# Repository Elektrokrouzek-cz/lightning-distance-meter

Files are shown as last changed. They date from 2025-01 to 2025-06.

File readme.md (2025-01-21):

# Lightning distance meter
This is the construction of lightning distance meter. It is based on NE555 timer 
and 4017 logical circuits. All components are in THT packages.

PCB is 2-layer and was designed using KiCad 8. Fabrication output for JLCPCB is in 
gerber folder.

## How it works
This meter measures distance between lightning and thunder by measuring the time.
Speed of sound is 343 m/s therefore it takes approx. 291ms to the sound to travel
100m (this is the period of NE555 timer). 
User pushes Start button when lightning occurs and then presses Stop button when 
hears the thunder. LED diodes show measured distance. Maximal measurable distance is 9.9km. 

**Happy soldering!**

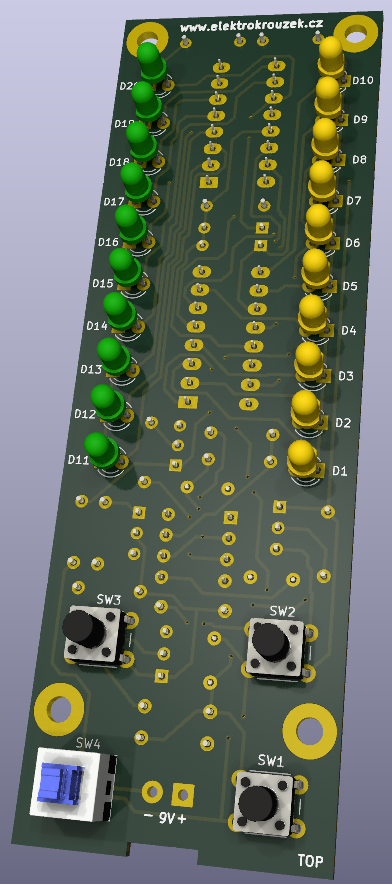
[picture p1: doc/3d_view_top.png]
3D view

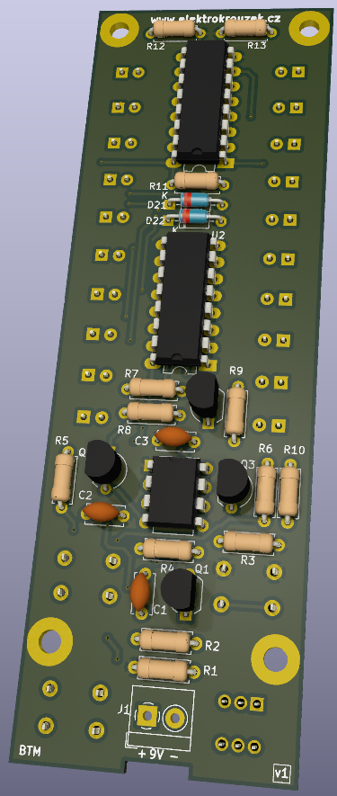
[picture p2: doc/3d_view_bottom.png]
3D view


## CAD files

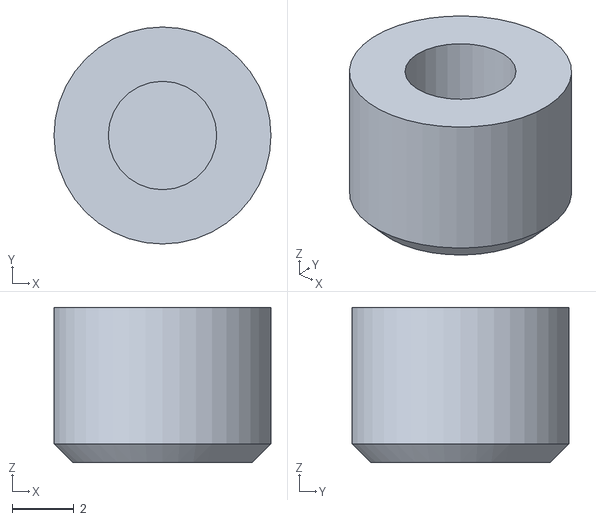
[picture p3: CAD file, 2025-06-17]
3d/storm_button.stl
7.00 x 7.00 x 5.00

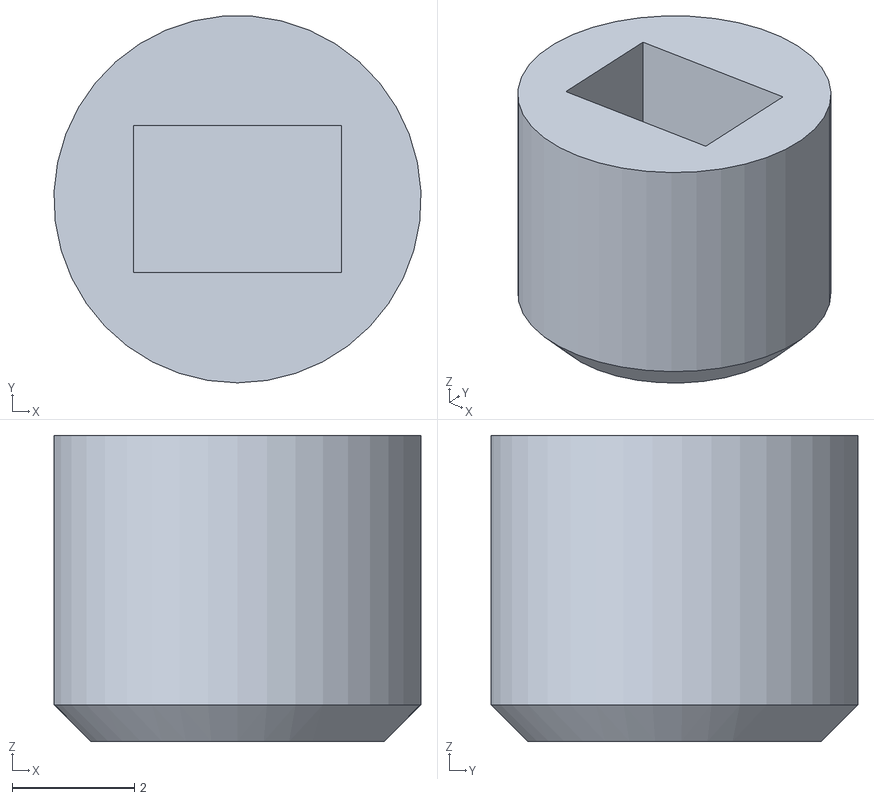
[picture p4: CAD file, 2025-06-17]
3d/storm_switch.stl
6.00 x 5.99 x 5.00

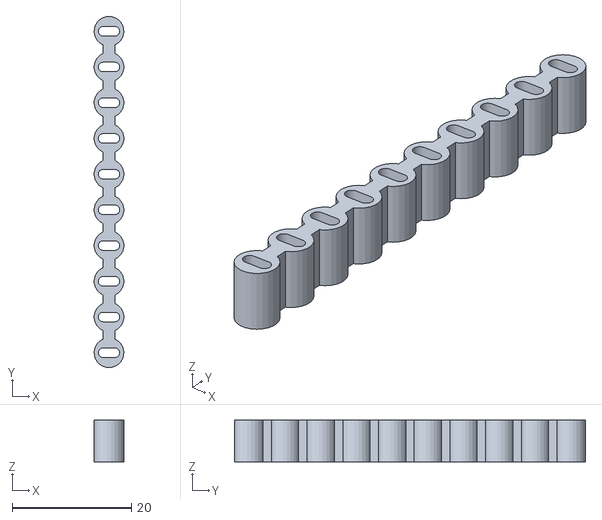
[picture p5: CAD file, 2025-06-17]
3d/storm_spacer.stl
4.96 x 59.0 x 7.00

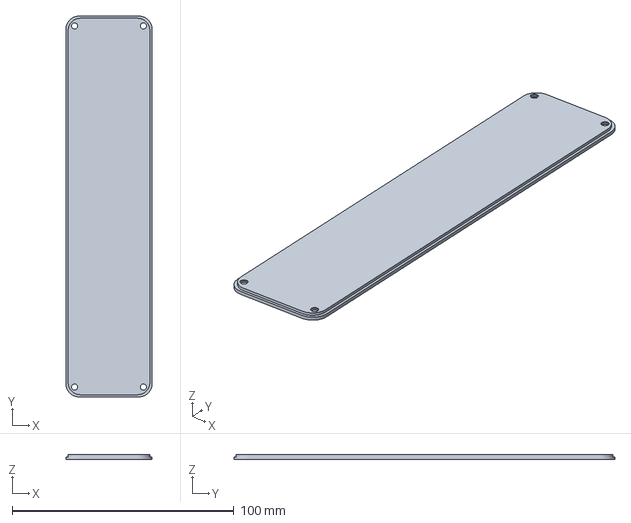
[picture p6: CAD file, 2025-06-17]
3d/storm_cover.3mf
39.0 x 172.0 x 2.20 mm

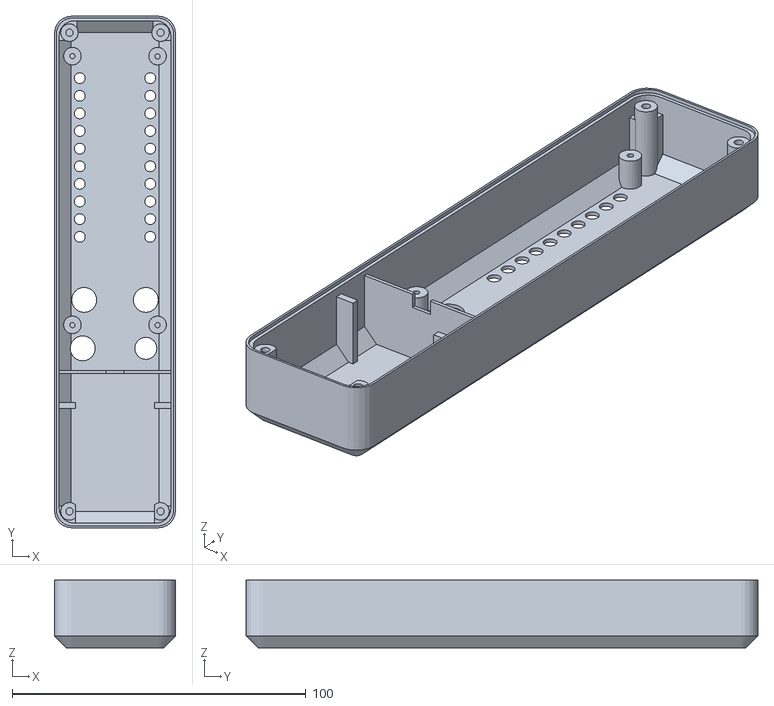
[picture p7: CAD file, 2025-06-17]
3d/storm_housing.stl
41.2 x 174.2 x 23.0

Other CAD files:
3d/storm.f3d

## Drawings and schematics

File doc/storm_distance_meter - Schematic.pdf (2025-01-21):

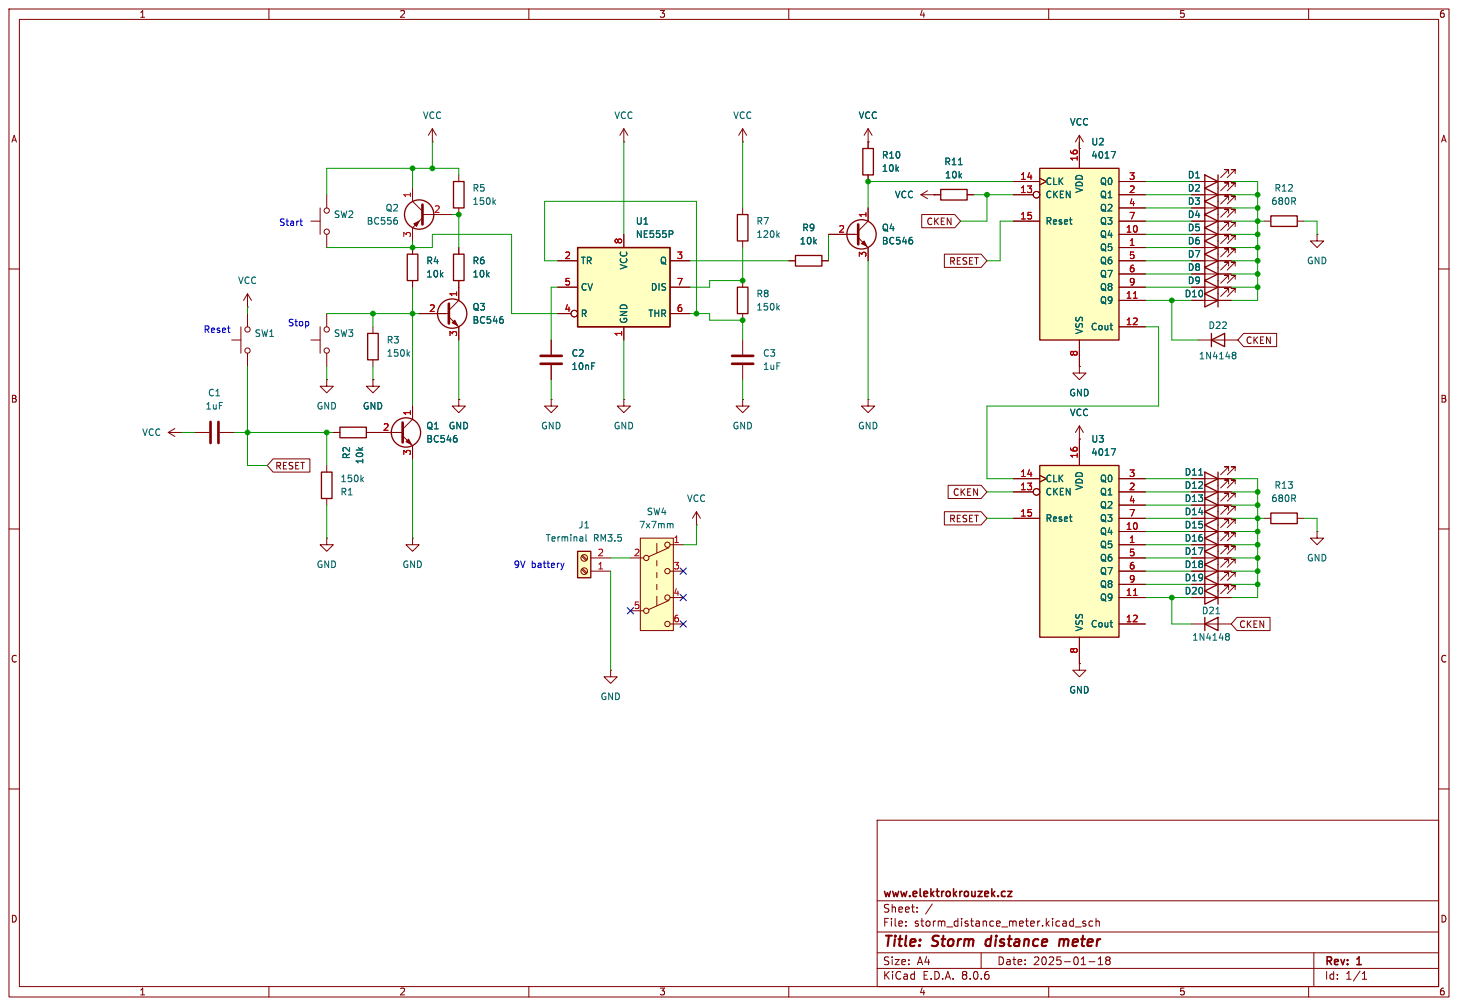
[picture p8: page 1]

3 Q3 BC546 VCC Q5 1 Q4 10 Q9 11 Cout 12 CKEN 13 CLK 14 Reset 15 VDD 16 Q1 2 Q0 3 Q2 4 Q6 5 Q7 6 Q3 7 VSS

Id: 1/1 Title: Storm distance meter File: storm_distance_meter.kicad_sch Sheet: / www.elektrokrouzek.cz

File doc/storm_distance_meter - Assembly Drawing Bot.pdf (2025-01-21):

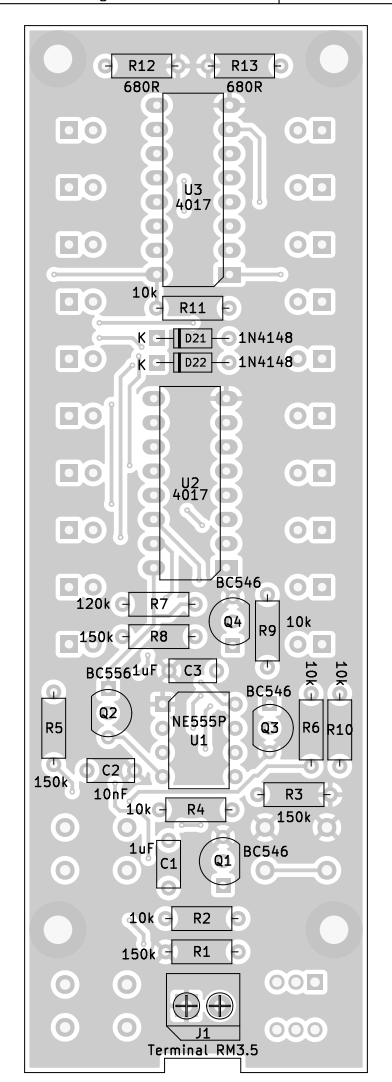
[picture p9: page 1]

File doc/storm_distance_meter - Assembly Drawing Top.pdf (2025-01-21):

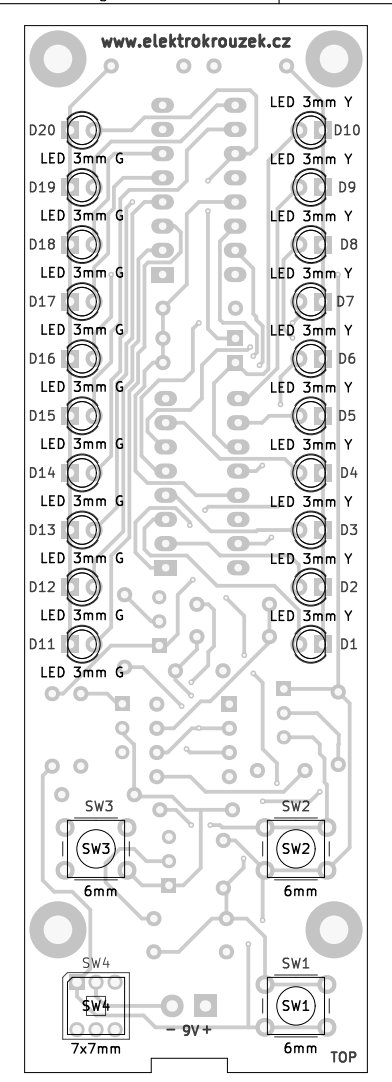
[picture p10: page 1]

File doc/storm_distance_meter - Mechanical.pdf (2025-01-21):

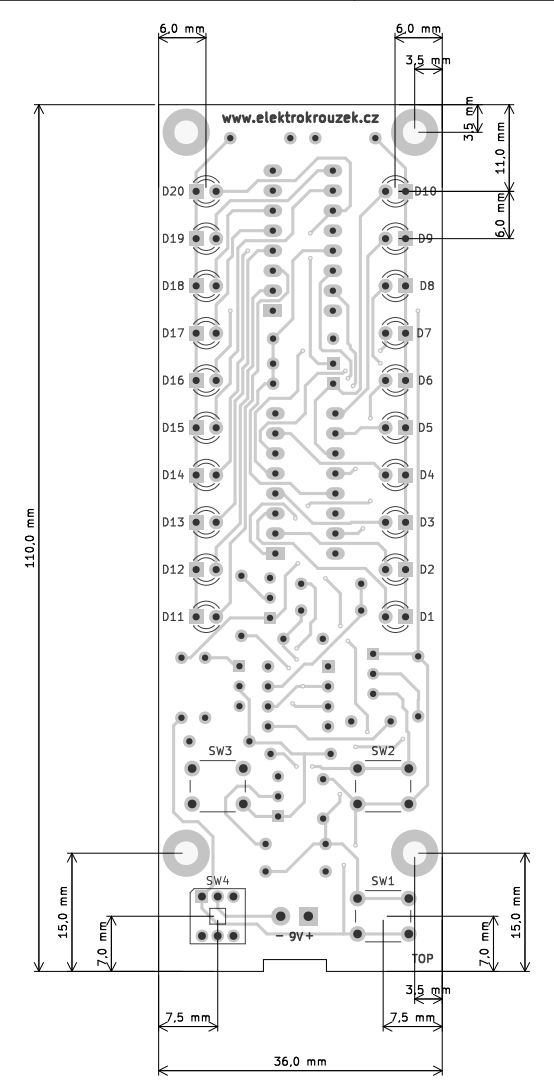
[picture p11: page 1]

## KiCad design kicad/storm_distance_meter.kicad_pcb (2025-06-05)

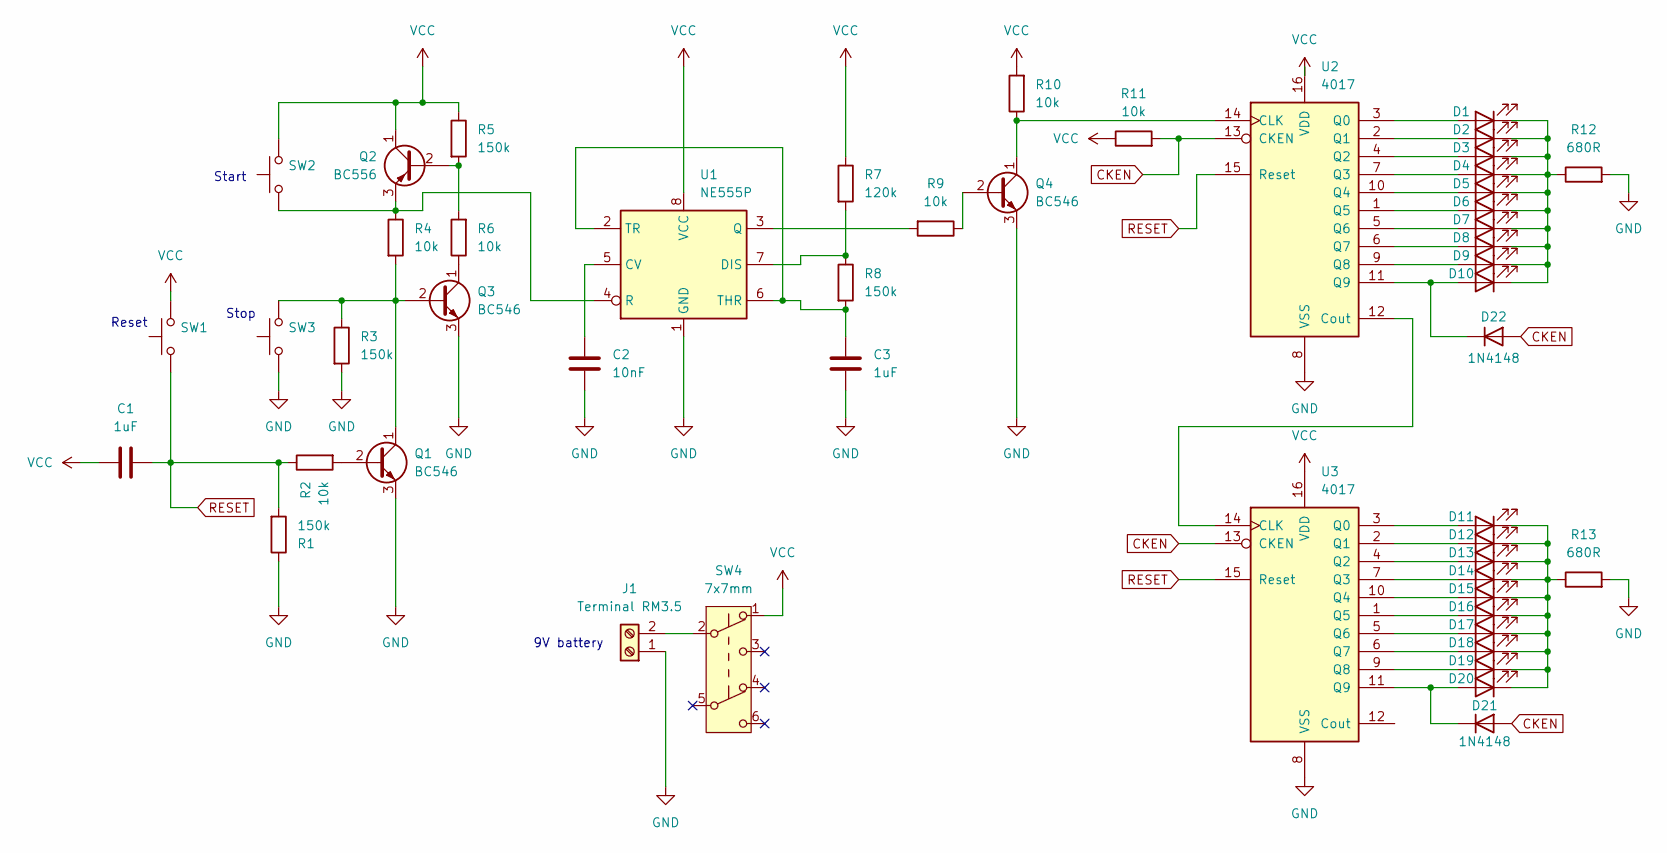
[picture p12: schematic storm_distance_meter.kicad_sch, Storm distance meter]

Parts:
C1, C3: 1uF; C_Disc_D5.0mm_W2.5mm_P5.00mm
C2: 10nF; C_Disc_D5.0mm_W2.5mm_P5.00mm
D1, D2, D3, D4, D5, D6, D7, D8, D9, D10: LED 3mm Y; LED_D3.0mm
D11, D12, D13, D14, D15, D16, D17, D18, D19, D20: LED 3mm G; LED_D3.0mm
D21, D22: 1N4148; D_DO-35_SOD27_P7.62mm_Horizontal
J1: Terminal RM3.5; TerminalBlock_4Ucon_1x02_P3.50mm_Horizontal
Q1, Q3, Q4: BC546; TO-92_Inline_Wide
Q2: BC556; TO-92_Inline_Wide
R1, R3, R5, R8: 150k; R_Axial_DIN0207_L6.3mm_D2.5mm_P7.62mm_Horizontal
R2, R4, R6, R9, R10, R11: 10k; R_Axial_DIN0207_L6.3mm_D2.5mm_P7.62mm_Horizontal
R7: 120k; R_Axial_DIN0207_L6.3mm_D2.5mm_P7.62mm_Horizontal
R12, R13: 680R; R_Axial_DIN0207_L6.3mm_D2.5mm_P7.62mm_Horizontal
SW1, SW2, SW3: 6mm; SW_PUSH_6mm_H9.5mm
SW4: 7x7mm; SW_DPDT_7x7_Turbo
U1: NE555P; DIP-8_W7.62mm
U2, U3: 4017; DIP-16_W7.62mm_LongPads

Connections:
CKEN: D21.2 (A), D22.2 (A), R11.2, U2.13 (CKEN), U3.13 (CKEN)
GND: C2.2, C3.2, J1.1, Q1.3 (E), Q3.3 (E), Q4.3 (E), R1.1, R3.2, R12.2, R13.2, SW3.1, U1.1 (GND), U2.8 (VSS), U3.8 (VSS)
unnamed: D1.2 (A), U2.3 (Q0)
unnamed: D1.1 (K), D2.1 (K), D3.1 (K), D4.1 (K), D5.1 (K), D6.1 (K), D7.1 (K), D8.1 (K), D9.1 (K), D10.1 (K), R12.1
unnamed: D2.2 (A), U2.2 (Q1)
unnamed: D3.2 (A), U2.4 (Q2)
unnamed: D4.2 (A), U2.7 (Q3)
unnamed: D5.2 (A), U2.10 (Q4)
unnamed: D6.2 (A), U2.1 (Q5)
unnamed: D7.2 (A), U2.5 (Q6)
unnamed: D8.2 (A), U2.6 (Q7)
unnamed: D9.2 (A), U2.9 (Q8)
unnamed: D10.2 (A), D22.1 (K), U2.11 (Q9)
unnamed: D11.2 (A), U3.3 (Q0)
unnamed: D11.1 (K), D12.1 (K), D13.1 (K), D14.1 (K), D15.1 (K), D16.1 (K), D17.1 (K), D18.1 (K), D19.1 (K), D20.1 (K), R13.1
unnamed: D12.2 (A), U3.2 (Q1)
unnamed: D13.2 (A), U3.4 (Q2)
unnamed: D14.2 (A), U3.7 (Q3)
unnamed: D15.2 (A), U3.10 (Q4)
unnamed: D16.2 (A), U3.1 (Q5)
unnamed: D17.2 (A), U3.5 (Q6)
unnamed: D18.2 (A), U3.6 (Q7)
unnamed: D19.2 (A), U3.9 (Q8)
unnamed: D20.2 (A), D21.1 (K), U3.11 (Q9)
unnamed: J1.2, SW4.2 (B)
unnamed: Q1.2 (B), R2.2
unnamed: Q1.1 (C), Q3.2 (B), R3.1, R4.2, SW3.2
unnamed: Q2.2 (B), R5.2, R6.2
unnamed: Q2.3 (E), R4.1, SW2.1, U1.4 (R)
unnamed: Q3.1 (C), R6.1
unnamed: Q4.2 (B), R9.1
unnamed: Q4.1 (C), R10.1, U2.14 (CLK)
unnamed: C2.1, U1.5 (CV)
unnamed: R7.2, R8.1, U1.7 (DIS)
unnamed: R9.2, U1.3 (Q)
unnamed: C3.1, R8.2, U1.2 (TR), U1.6 (THR)
unnamed: U2.12 (Cout), U3.14 (CLK)
RESET: C1.2, R1.2, R2.1, SW1.1, U2.15 (Reset), U3.15 (Reset)
VCC: C1.1, Q2.1 (C), R5.1, R7.1, R10.2, R11.1, SW1.2, SW2.2, SW4.1 (A), U1.8 (VCC), U2.16 (VDD), U3.16 (VDD)

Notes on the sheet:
Reset
9V battery
Stop
Start

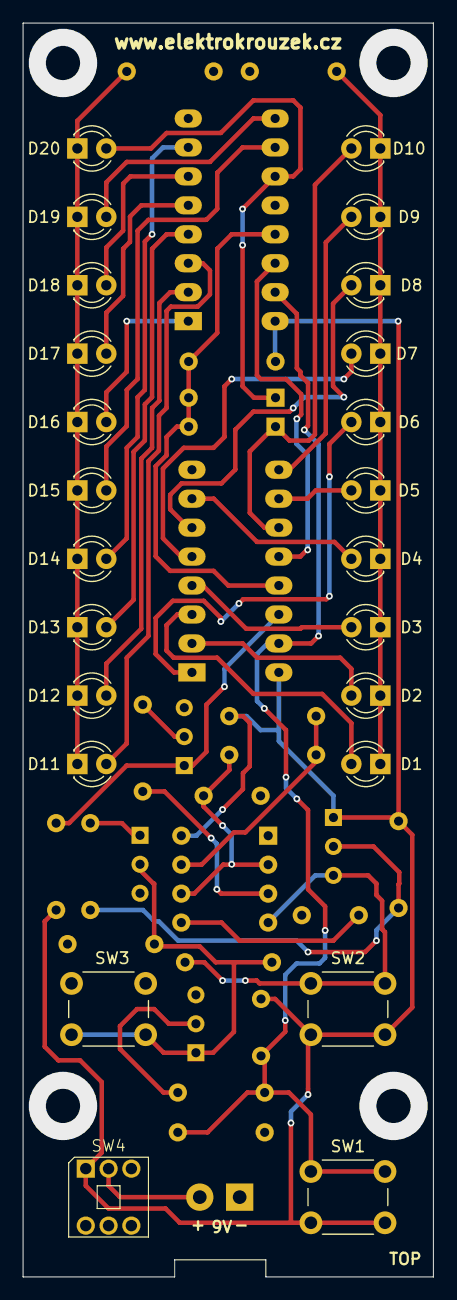
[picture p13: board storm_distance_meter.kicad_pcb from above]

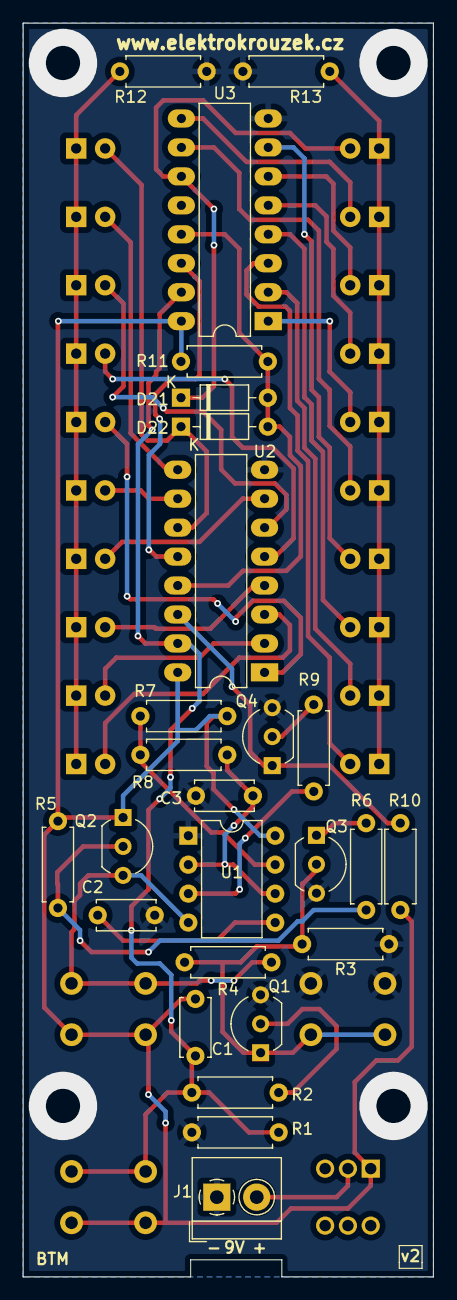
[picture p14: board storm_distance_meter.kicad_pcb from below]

Board: 2 copper layers, 36.0 x 110.0 mm, 50 parts (26 on the bottom side), 39 nets.

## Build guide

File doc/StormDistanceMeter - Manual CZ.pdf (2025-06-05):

www.elektrokrouzek.cz

## Měřič vzdálenosti bouřky

## Popis zapojení

Tato konstrukce měří a ukazuje vzdálenosti úderu blesku měřením času mezi bleskem a hromem v rozmezí 0 až 9.9 km.
Při spatření blesku uživatel stiskne tlačítko Start, čítač začne počítat v periodě 100m (291ms). Po zaslechnutí hromu uživatel stiskne tlačítko Stop a čítání se zastaví. Levý sloupec LED diod znázorňuje vzdálenost blesku s rozlišením 1km, pravý sloupec s rozlišením 100m.
Konstrukce je založena na časovači 555 zapojeným jako astabilní klopný obvod s periodou cca 291ms. Hodinový signál je přiveden do dvojice Johnsonových čítačů 4017 zapojených do kaskády.
Tlačítka Start a Stop ovládají bistabilní klopný obvod tvořený tranzistory Q2 a Q3. Tlačítko Start zároveň resetuje časovač 555.
Tlačítko Reset resetuje čítače 4017 do stavu 0m a zároveň přepíná bistabilní klopný obvod do stavu Stop.

## Popis sestavení

Konstrukce má součástky z obou stran plošného spoje. Nejprve osazujeme součástky ze spodní strany (bottom). Začneme rezistory, pokračujeme diodami D21 a D22, dále paticemi pro IO. Dále osadíme keramické kondenzátory, tranzistory a nakonec svorkovnici.
Pokračujeme druhou stranou plošného spoje (top). Osadíme LED diody, jejichž poloha je vymezena plastovými vymezovači. Vždy je lepší nejprve vyskládat všechny LED diody ve sloupci a teprve poté je zapájet. Vyvarujeme se tak možnému roztavení a uhnutí plastového vymezovače.
Na závěr osadíme tlačítka a vypínač. Pozor na orientaci vypínače – viz obrázek.

## Oživení

Pokud jste pracovali pečlivě mělo by zapojení fungovat na první pokus. Po zapnutí by měly svítit LED diody s údajem 0km a 0m.

## Seznam součástek

Označení | Hodnota | Počet
C1,C3 | 1uF | 2
C2 | 10nF | 1
D1,D2,D3,D4,D5,D6,D7,D8,D9,D10 | LED 3mm Y | 10
D11,D12,D13,D14,D15,D16,D17,D18,D19,D20 | LED 3mm G | 10
D21,D22 | 1N4148 | 2
J1 | Terminal RM3.5 | 1
Q1,Q3,Q4 | BC546 | 3
Q2 | BC556 | 1
R1,R3,R5,R8 | 150k | 4
R2,R4,R6,R9,R10,R11 | 10k | 6
R7 | 120k | 1
R12,R13 | 680R | 2
SW1,SW2,SW3 | 6mm | 3
SW4 | 7x7mm | 1
U1 | NE555P | 1
U2,U3 | 4017 | 2

## Orientace vypínače

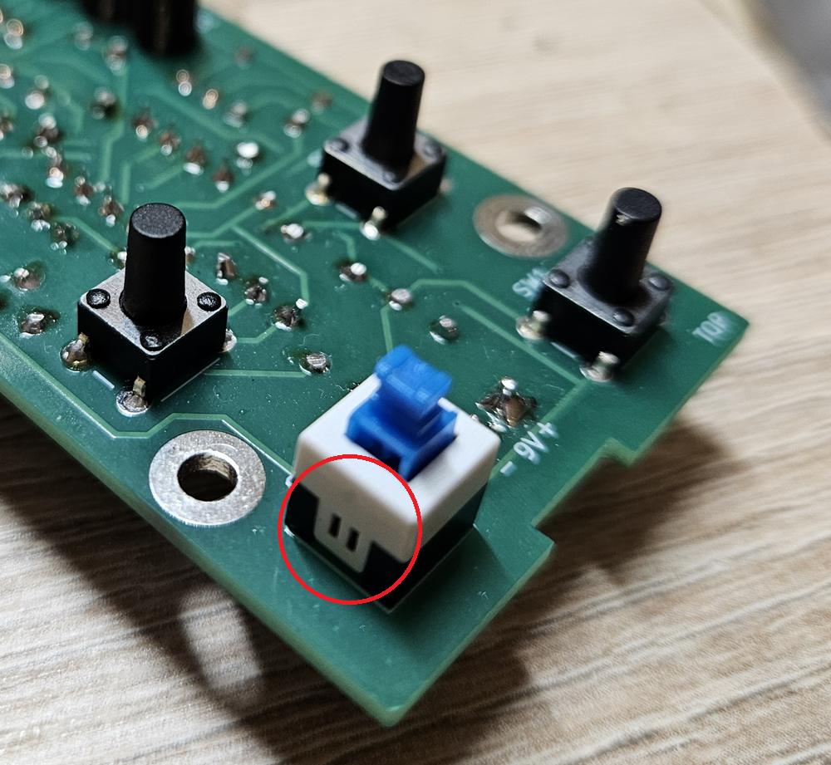
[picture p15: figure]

## Plastové vymezovače LED diod

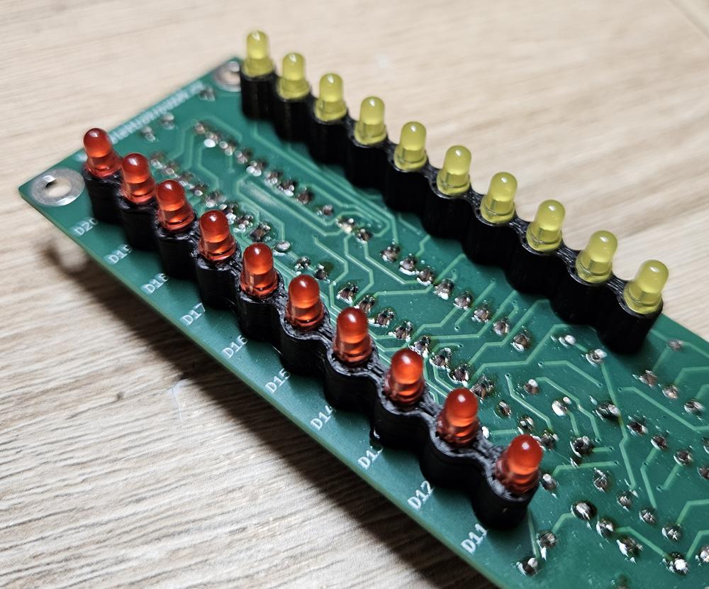
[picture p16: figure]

## Osazovací výkresy

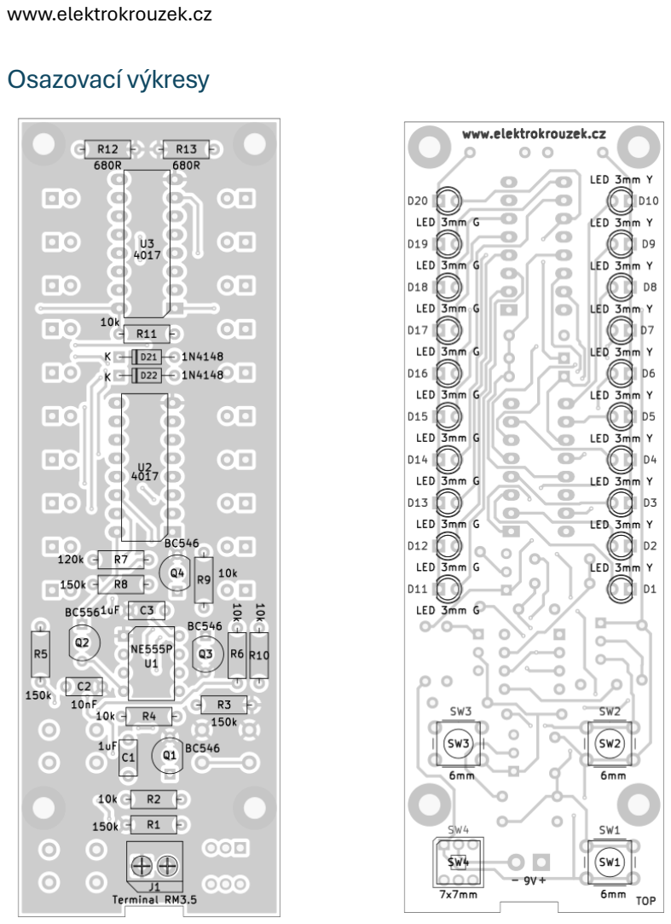
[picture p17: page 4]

## Schéma zapojení

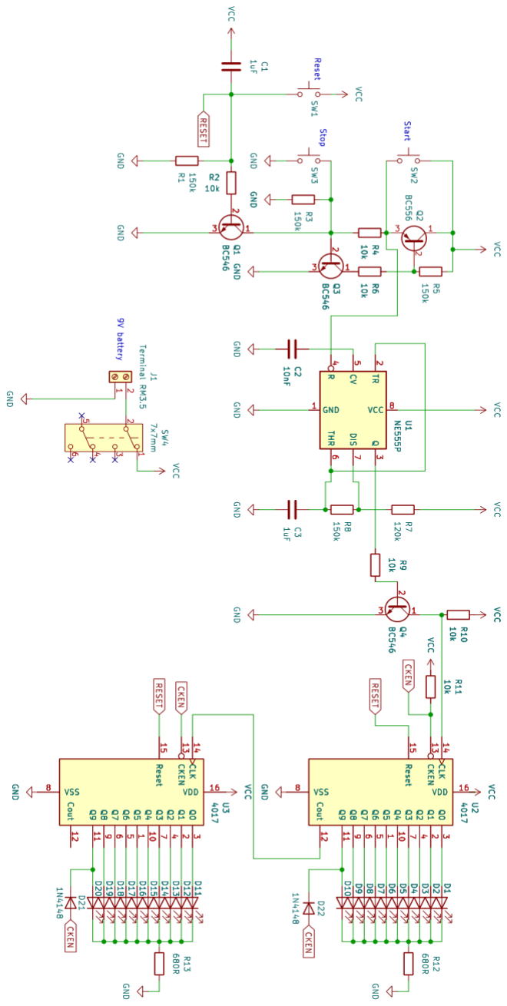
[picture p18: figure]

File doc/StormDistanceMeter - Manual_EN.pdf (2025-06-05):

www.elektrokrouzek.cz

## Lightning distance meter

## Schematic description

This construction measures and displays the distance between lightning and thunder within range of 0 to 9.9km
When lightning occurs the user presses Start button, and the counter starts to count in a period of 100m (291ms). When thunder occurs the user presses Stop button and counting stops. Left LED column displays lightning distance with 1km resolution and right column with 100m resolution.
Construction is based on 555 timer connected as astable flip flop with approximately 291ms period. Clock signal is connected to 2 4017 Johnson counters connected in cascade.
Start and Stop buttons control bistable flip flop created of Q2 and Q3 transistors. Start button also resets the 555 timer.
Reset button resets both 4017 timers to 0m state and also switches the bistable flip flop to Stop state.

## Construction

Construction has components placed on both sides of the PCB. We populate components from bottom PCB side first. We start with resistors, then continue with diodes D21 and D22, then IC sockets. Then we populate ceramic capacitors, transistors and finish with terminal.
Then we continue with other side of PCB – top. We populate LED diodes that are placed in plastic spacers. Its better to place all LED diodes to PCB with spacer and then solder them all - we avoid melting and moving plastic spacers.
Finally, we populate buttons and switch. Caution – take care of switch orientation – see picture.

## How to get it into service

It should work on the first try when everything was soldered well. The device should show 0km and 0m distance after turning on.

## Bill of materials

Annotation | Value | Qty
C1,C3 | 1uF | 2
C2 | 10nF | 1
D1,D2,D3,D4,D5,D6,D7,D8,D9,D10 | LED 3mm Y | 10
D11,D12,D13,D14,D15,D16,D17,D18,D19,D20 | LED 3mm G | 10
D21,D22 | 1N4148 | 2
J1 | Terminal RM3.5 | 1
Q1,Q3,Q4 | BC546 | 3
Q2 | BC556 | 1
R1,R3,R5,R8 | 150k | 4
R2,R4,R6,R9,R10,R11 | 10k | 6
R7 | 120k | 1
R12,R13 | 680R | 2
SW1,SW2,SW3 | 6mm | 3
SW4 | 7x7mm | 1
U1 | NE555P | 1
U2,U3 | 4017 | 2

## Switch orientation


## LED diodes spacers


## PCB assembly

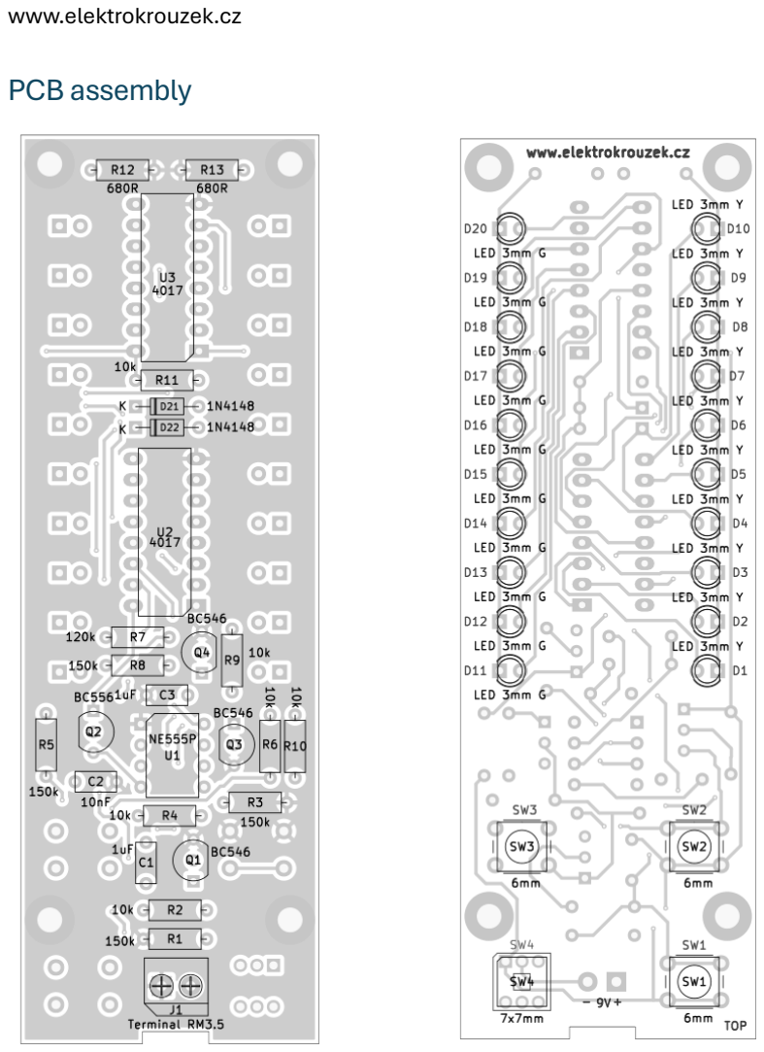
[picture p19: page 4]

## Schematic


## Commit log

2025-01-21 PDF schematic added
2025-06-05 Updated PCB, manuals
    [storm_distance_meter-B_Cu.gbl, storm_distance_meter-B_Mask.gbs, storm_distance_meter-B_Paste.gbp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]
2025-06-17 3D models
    [storm.f3d, storm_button.stl, storm_cover.3mf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]
